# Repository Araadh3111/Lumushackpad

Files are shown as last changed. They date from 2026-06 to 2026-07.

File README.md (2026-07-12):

# Lumuspad

A 5-key macropad with a rotary encoder, OLED screen and RGB underglow.
Based on HackClub's MacroPad Guide: https://hackpad.hackclub.com/guide

----------------------------------
What it does:-

- SW1: New tab (Ctrl+T)
- SW2: Cycles the OLED animation (Cyberpunk scanner / Equalizer / Stealth logo)
- SW3: Launches VS Code
- SW4: Opens YouTube in Brave
- SW5: Leaves the current call (Zoom / Teams / Discord)
- Knob: Volume up/down, press to mute
- 5x SK6812 RGB LEDs running a rainbow swirl

----------------------------------
File Structure:-

--CAD

  -luma_bottom_tray.step

  -luma_spacer.step

  -luma_switch_plate.step

  -luma_case_assembled.step

--Firmware (QMK, builds automatically via GitHub Actions -> .uf2)

  -keyboard.json

  -keymap.c

  -config.h

  -rules.mk

--PCB (schematics + pcb)

  -Luma pcb.kicad_pro / .kicad_sch / .kicad_pcb

----------------------------------
Schematic:-

Heres my schematic I forgot to organise :(



PCB:-
Here is my pcb I imported the silkscreen from pinterest then used inbuilt image converter to copy it and paste it on the pcb

PS:- the led dioded do not intersect with the switch as they are inverted and on the other side! more can be seen from the next two screenshots





Case:-
here is my case, I was aiming for one cyberpunkish case and made it its screwable from the corners(m3 screws)


Assembled:-
here is the assembled file! (ps: the pins will be bended!)


---------------------------------
Ai usage:-
I used claude to help me make the qmk firmware! rest build was done by me
----------------------------------
BOM:-

-1x Seeed XIAO RP2040

-5x MX-style Switches

-5x DSA Keycaps

-1x EC11 Rotary Encoder (with push button)

-1x 0.91" 128x32 OLED Display (I2C)

-5x SK6812 MINI RGB LEDs

-1x Resistor (RGB data line)

-5x 100nF Capacitors and one μF Capacitor in the pcb

-1x Case (3 printed parts: bottom tray, spacer, switch plate)

No diodes needed — every switch has its own pin (direct wiring).

refer to BOM.CSV
+ pcb printing fund

----------------------------------
Firmware:-

Compiled automatically by GitHub Actions on every push.
Grab the latest lumuspad_firmware artifact from the Actions tab,
hold the BOOT button on the XIAO while plugging in USB,
and drag the .uf2 onto the RPI-RP2 drive.
----------------------------------

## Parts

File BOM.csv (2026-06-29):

Quantity | Part | Notes
1 | Seeed XIAO RP2040
5 | MX-style Switches
5 | DSA Keycaps
1 | EC11 Rotary Encoder | With push button
1 | 0.91" 128x32 OLED Display | I2C
5 | SK6812 MINI RGB LEDs
1 | Resistor | RGB data line
5 | 100nF Capacitors | In the PCB
1 | µF Capacitor | In the PCB
1 | Case | 3 printed parts: bottom tray, spacer, switch plate

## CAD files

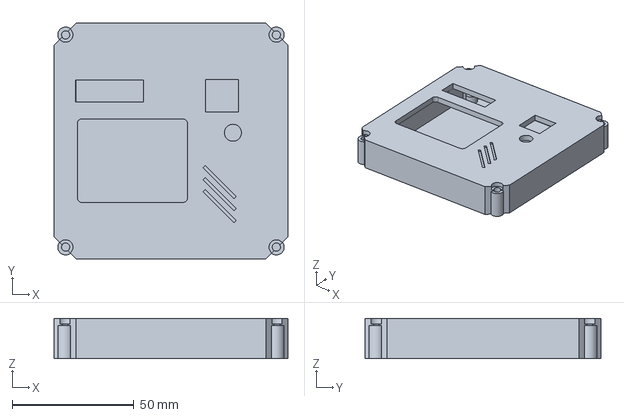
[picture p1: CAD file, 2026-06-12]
CAD/luma_case_assembled.step
96.2 x 96.9 x 16.5 mm

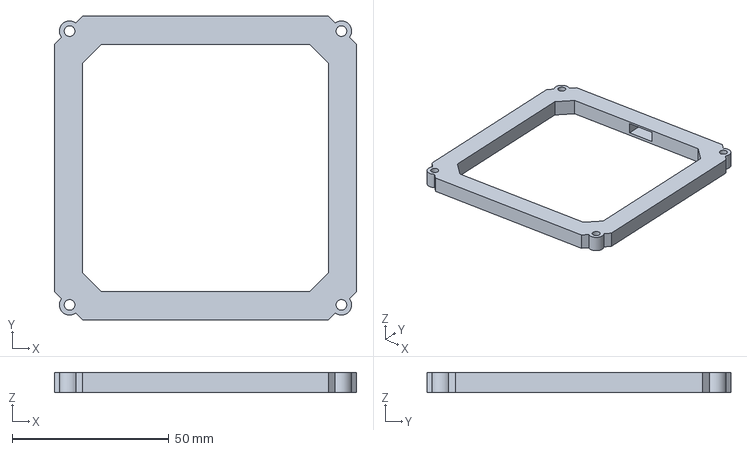
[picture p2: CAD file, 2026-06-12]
Production/luma_spacer.step
96.2 x 96.9 x 6.50 mm

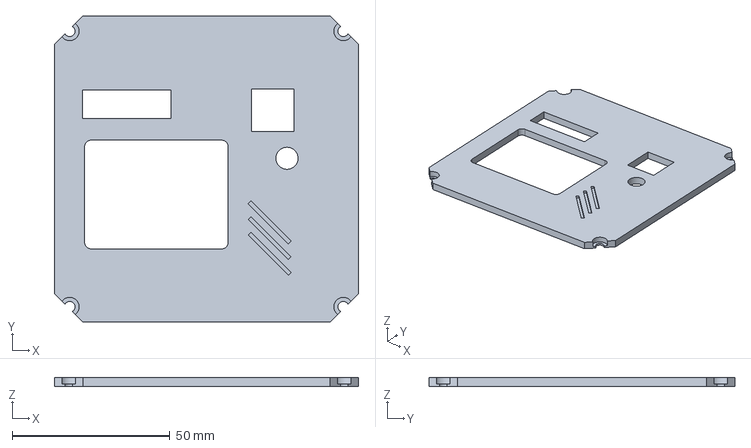
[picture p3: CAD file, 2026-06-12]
Production/luma_switch_plate.step
96.2 x 96.9 x 3.00 mm

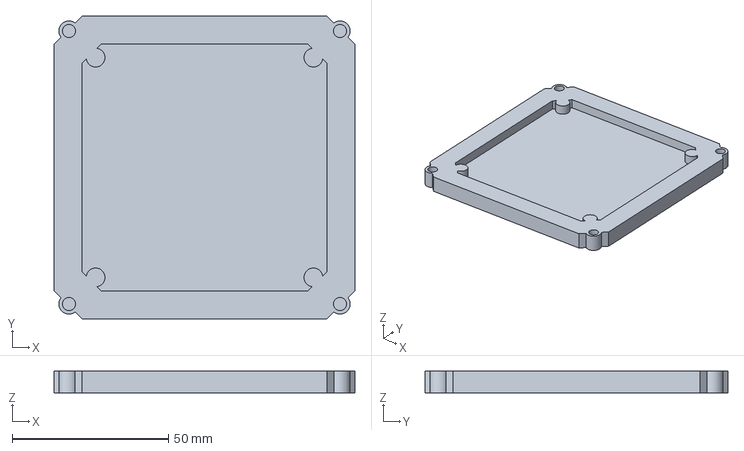
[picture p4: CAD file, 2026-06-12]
Production/luma_bottom_tray.step
96.2 x 96.9 x 7.00 mm

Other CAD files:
CAD/luma_bottom_tray.f3d

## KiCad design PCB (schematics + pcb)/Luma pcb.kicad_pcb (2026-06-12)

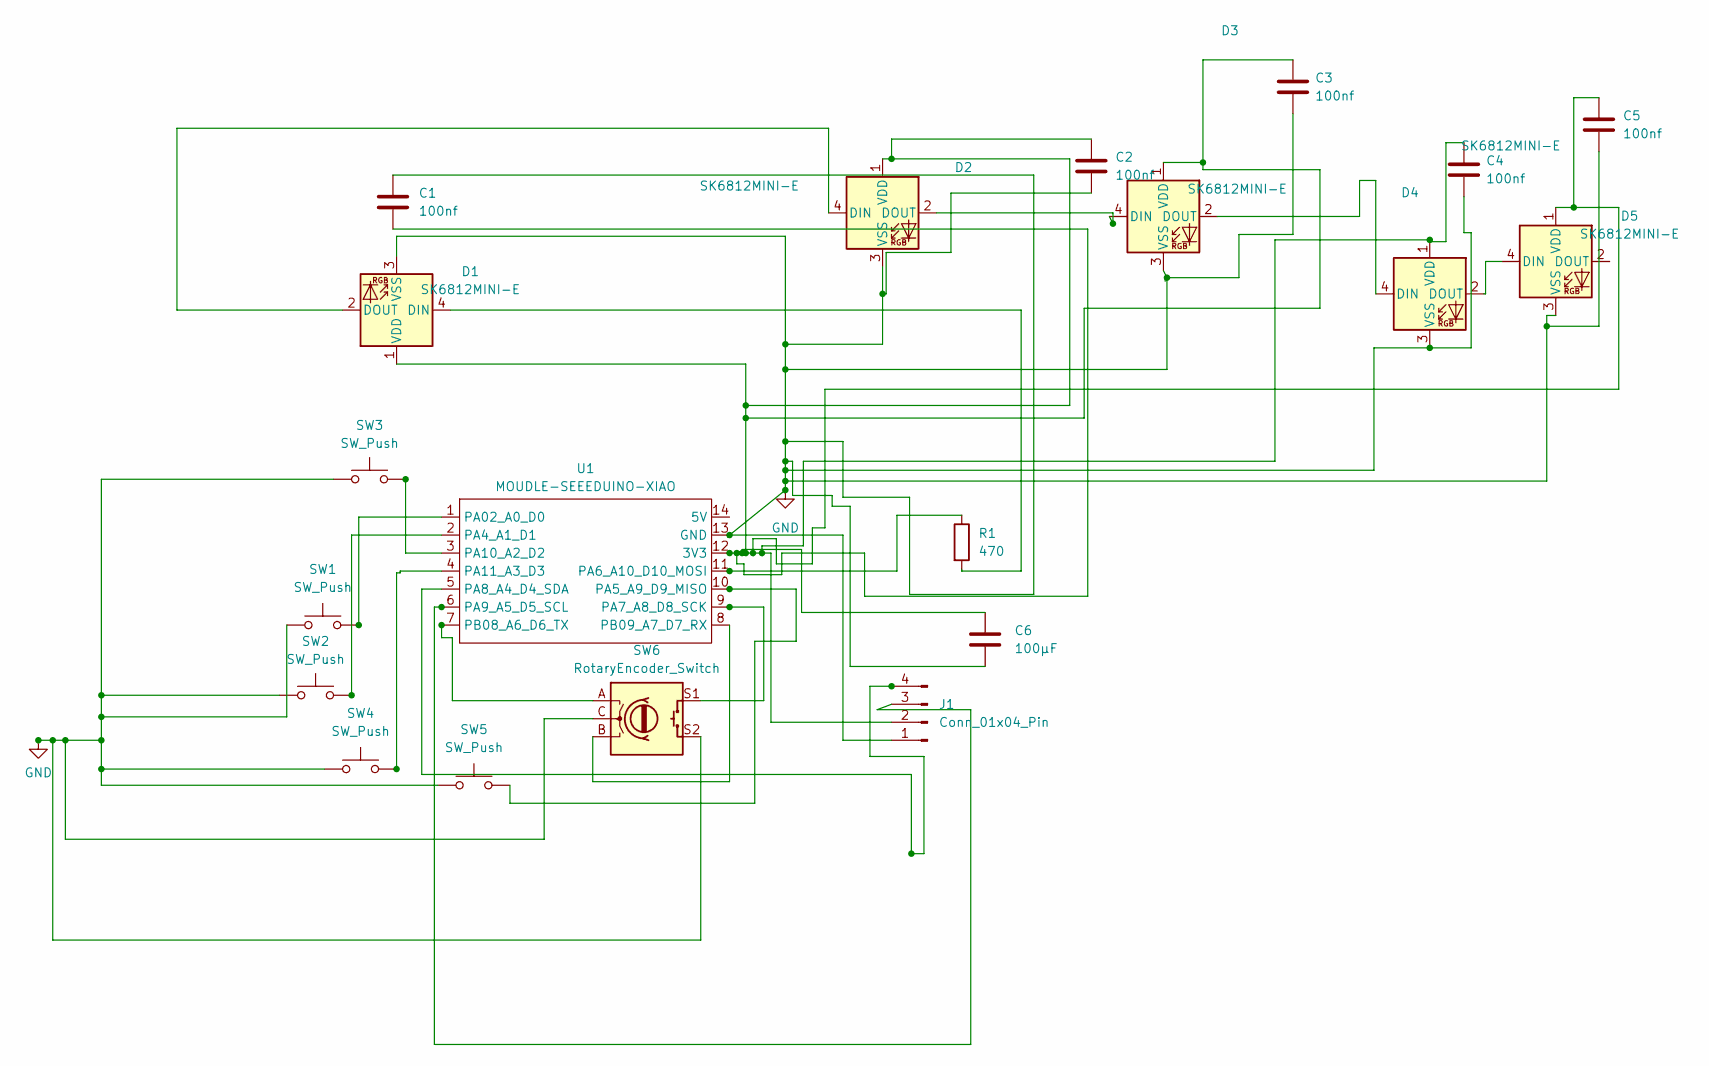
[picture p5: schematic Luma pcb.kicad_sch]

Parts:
C1, C2, C3, C4, C5: 100nf; C_0805_2012Metric_Pad1.18x1.45mm_HandSolder
C6: 100µF; CP_Radial_D5.0mm_P2.00mm
D1, D2, D3, D4, D5: SK6812MINI-E; SK6812MINI-E_fixed
J1: Conn_01x04_Pin; FanPinHeader_1x04_P2.54mm_Vertical
R1: 470; R_Axial_DIN0207_L6.3mm_D2.5mm_P7.62mm_Horizontal
SW1, SW2, SW3, SW4, SW5: SW_Push; SW_Cherry_MX_1.00u_PCB
SW6: RotaryEncoder_Switch; RotaryEncoder_Alps_EC11E-Switch_Vertical_H20mm
U1: MOUDLE-SEEEDUINO-XIAO; XIAO-Generic-Hybrid-14P-2.54-21X17.8MM

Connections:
GND: C1.1, C2.2, C3.2, C4.2, C5.2, C6.2, D1.3 (VSS), D2.3 (VSS), D3.3 (VSS), D4.3 (VSS), D5.3 (VSS), J1.1, SW1.1, SW2.1, SW3.1, SW4.1, SW5.1, SW6.C, SW6.S2, U1.13 (GND)
unnamed: D1.4 (DIN), R1.2
unnamed: D1.2 (DOUT), D2.4 (DIN)
unnamed: C1.2, C2.1, C3.1, C4.1, C5.1, C6.1, D1.1 (VDD), D2.1 (VDD), D3.1 (VDD), D4.1 (VDD), D5.1 (VDD), J1.2, U1.12 (3V3)
unnamed: D2.2 (DOUT), D4.4 (DIN)
unnamed: D3.4 (DIN), D4.2 (DOUT)
unnamed: D3.2 (DOUT), D5.4 (DIN)
unnamed: J1.3, U1.6 (PA9_A5_D5_SCL)
unnamed: J1.4, U1.5 (PA8_A4_D4_SDA)
unnamed: SW1.2, U1.1 (PA02_A0_D0)
unnamed: SW2.2, U1.2 (PA4_A1_D1)
unnamed: SW5.2, U1.10 (PA5_A9_D9_MISO)
unnamed: R1.1, U1.11 (PA6_A10_D10_MOSI)
unnamed: SW6.S1, U1.9 (PA7_A8_D8_SCK)
unnamed: SW3.2, U1.3 (PA10_A2_D2)
unnamed: SW4.2, U1.4 (PA11_A3_D3)
unnamed: SW6.A, U1.7 (PB08_A6_D6_TX)
unnamed: SW6.B, U1.8 (PB09_A7_D7_RX)

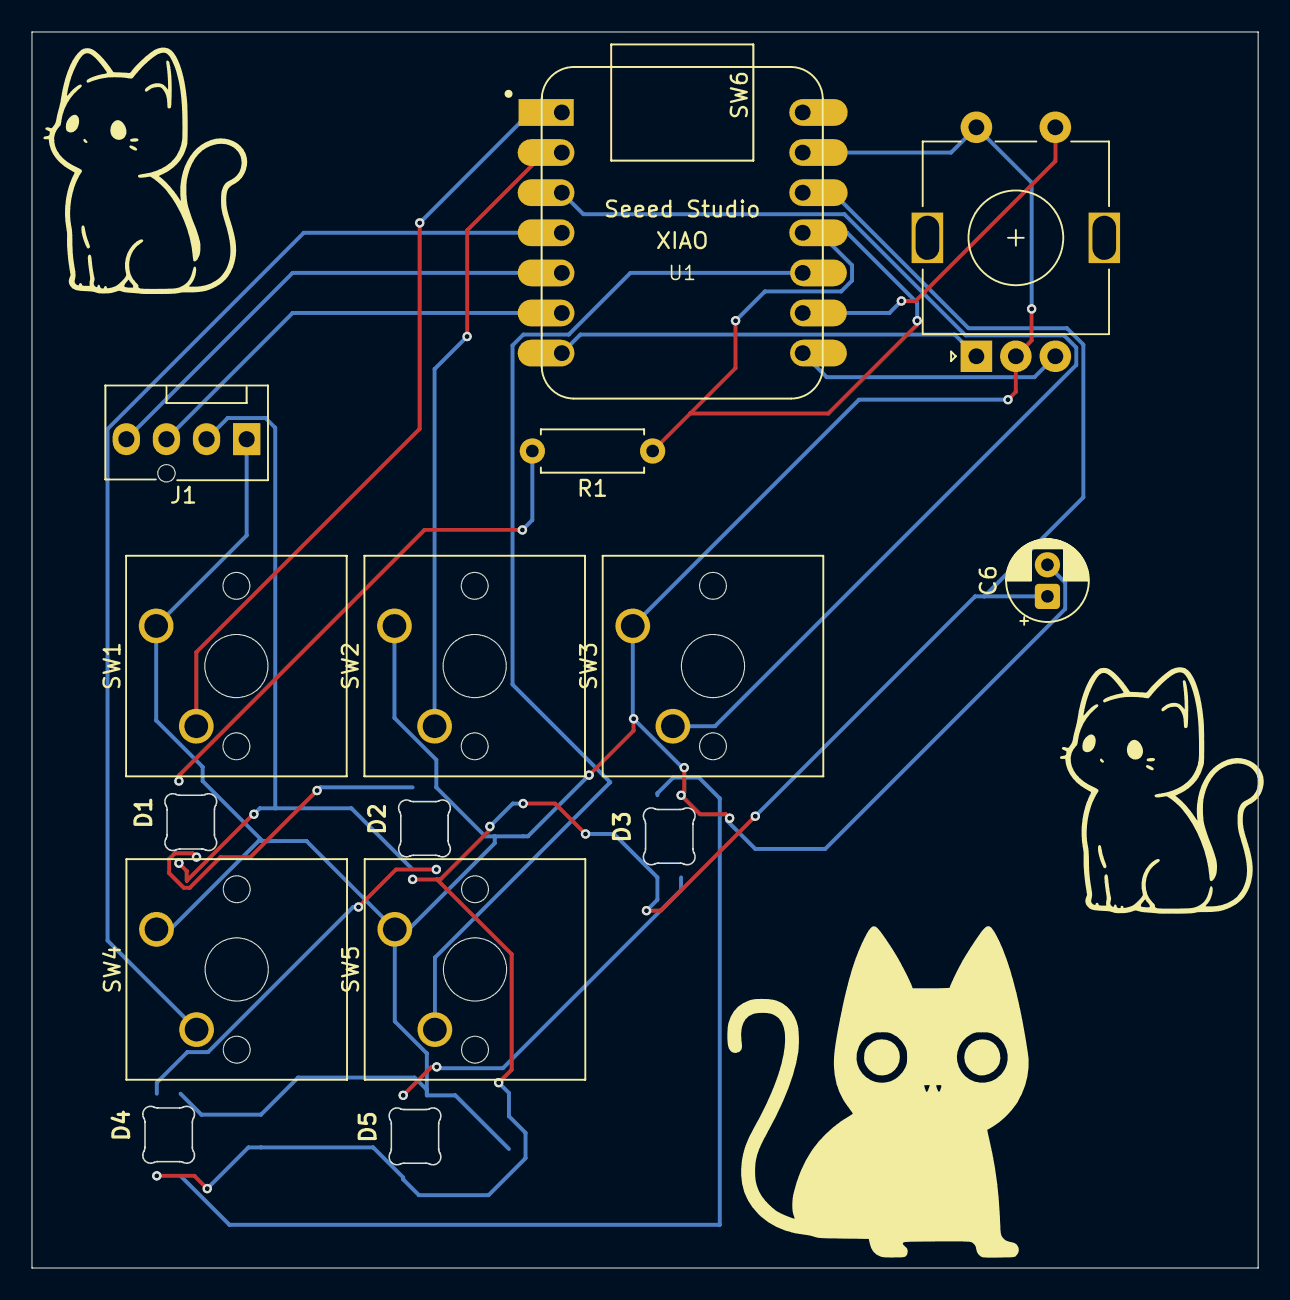
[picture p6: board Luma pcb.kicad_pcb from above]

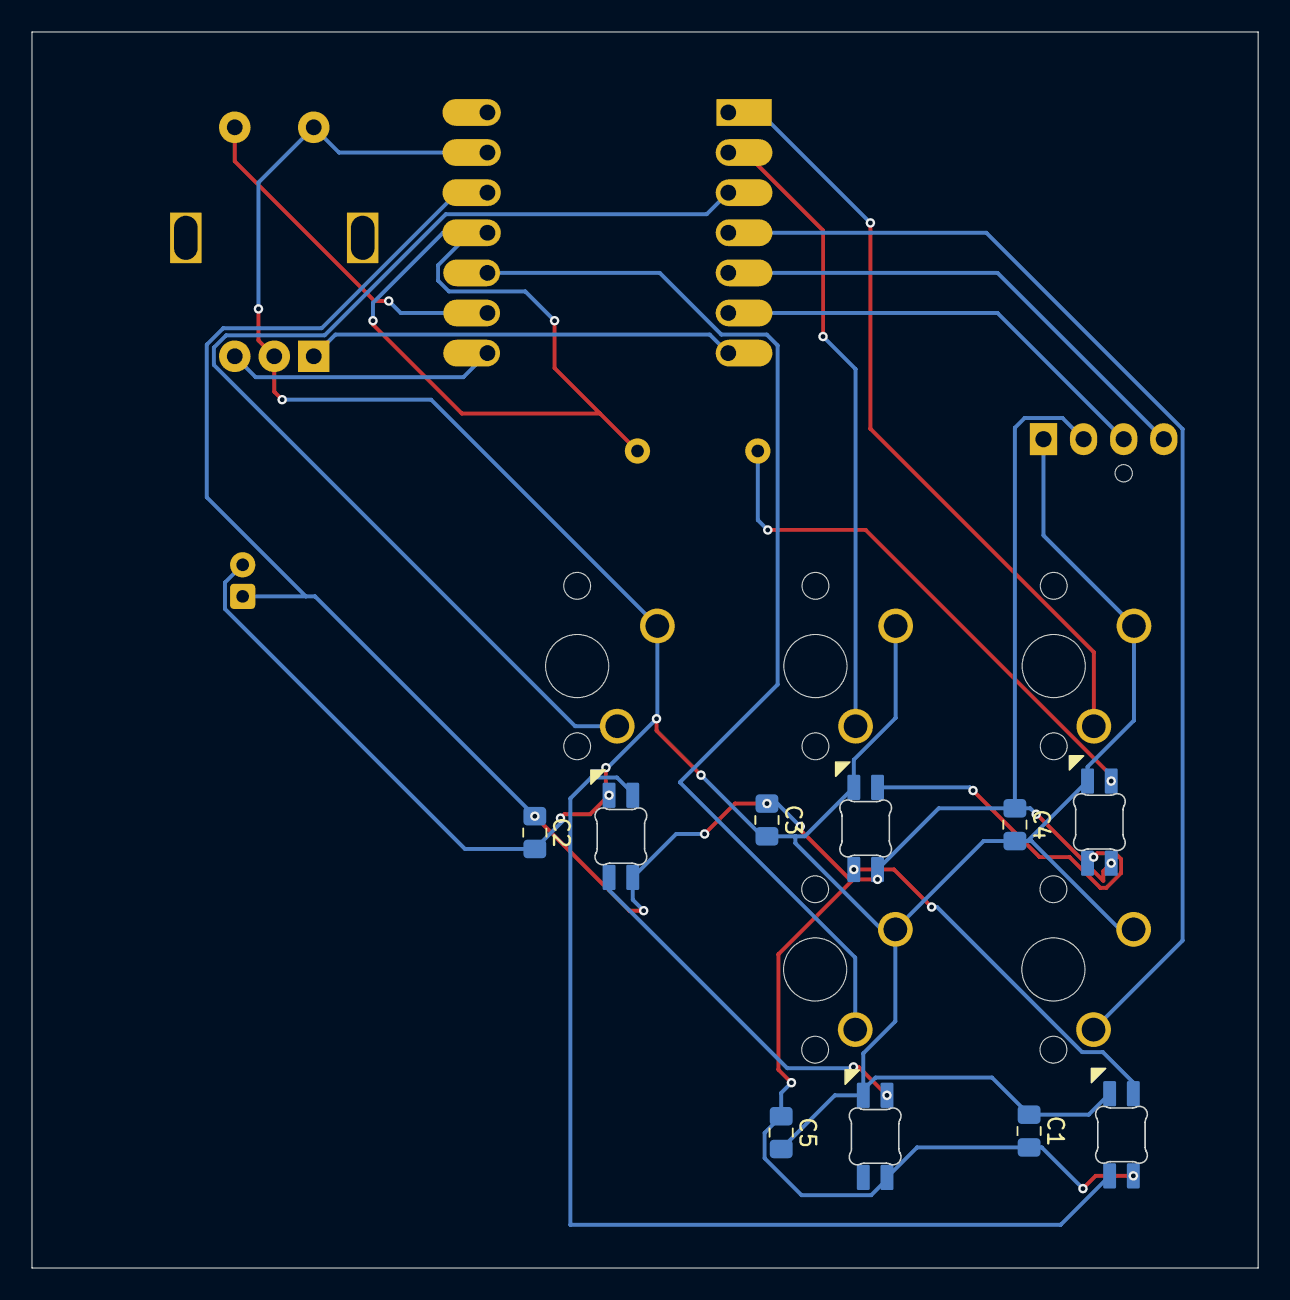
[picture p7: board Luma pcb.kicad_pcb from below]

Board: 2 copper layers, 77.6 x 78.3 mm, 20 parts (5 on the bottom side), 18 nets.

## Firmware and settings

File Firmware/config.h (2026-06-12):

#pragma once

// OLED sits on the XIAO RP2040 hardware I2C: D4/SDA = GP6, D5/SCL = GP7 (I2C1)
#define I2C_DRIVER I2CD1
#define I2C1_SDA_PIN GP6
#define I2C1_SCL_PIN GP7

// 0.91" SSD1306, 128x32
#define OLED_BRIGHTNESS 128
#define OLED_TIMEOUT 60000

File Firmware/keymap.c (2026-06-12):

#include QMK_KEYBOARD_H
#include <stdio.h>

// Custom keycodes for app-launcher macros and the OLED mode switch
enum custom_keycodes {
    OPEN_VSCODE = SAFE_RANGE,
    OPEN_BRAVE_YT,
    LEAVE_CALL,
    ANIM_CYCLE
};

// Physical order matches the direct-pin matrix in keyboard.json:
// SW1..SW5 are the keys, SW6 is the rotary encoder's push button.
const uint16_t PROGMEM keymaps[][MATRIX_ROWS][MATRIX_COLS] = {
    [0] = LAYOUT(
        LCTL(KC_T),       // SW1: New Tab (Ctrl + T)
        ANIM_CYCLE,       // SW2: Cycle OLED animation mode
        OPEN_VSCODE,      // SW3: Launch VS Code
        OPEN_BRAVE_YT,    // SW4: Open YouTube in Brave
        LEAVE_CALL,       // SW5: Leave call (Zoom / Teams / Discord)
        KC_MUTE           // SW6: Encoder push = mute audio
    )
};

// ---------------------------------------------------------------------------
// Shared state for the OLED status line
// ---------------------------------------------------------------------------
static uint8_t anim_mode = 0;
static char    last_action[12] = "READY";

static void set_action(const char *name) {
    snprintf(last_action, sizeof(last_action), "%s", name);
}

// ---------------------------------------------------------------------------
// Macros: launch apps through the Windows Run dialog (Win+R)
// ---------------------------------------------------------------------------
bool process_record_user(uint16_t keycode, keyrecord_t *record) {
    if (!record->event.pressed) {
        return true;
    }

    switch (keycode) {
        case ANIM_CYCLE:
            anim_mode = (anim_mode + 1) % 3;
            return false;

        case OPEN_VSCODE:
            SEND_STRING(SS_LGUI("r") SS_DELAY(150) "code" SS_TAP(X_ENTER));
            set_action("VSCODE");
            return false;

        case OPEN_BRAVE_YT:
            SEND_STRING(SS_LGUI("r") SS_DELAY(150) "brave youtube.com" SS_TAP(X_ENTER));
            set_action("YOUTUBE");
            return false;

        case LEAVE_CALL:
            // Zoom end-call first, then a Ctrl+Shift+H backup for Teams/Discord
            SEND_STRING(SS_LALT("h") SS_DELAY(50) SS_LCTL(SS_LSFT("h")));
            set_action("END CALL");
            return false;

        case LCTL(KC_T):
            set_action("NEW TAB");
            return true;

        case KC_MUTE:
            set_action("MUTE");
            return true;
    }
    return true;
}

// ---------------------------------------------------------------------------
// Rotary encoder: volume control
// ---------------------------------------------------------------------------
#ifdef ENCODER_ENABLE
bool encoder_update_user(uint8_t index, bool clockwise) {
    if (clockwise) {
        tap_code(KC_VOLU);
        set_action("VOL +");
    } else {
        tap_code(KC_VOLD);
        set_action("VOL -");
    }
    return false;
}
#endif

// ---------------------------------------------------------------------------
// OLED: three animated modes on the 128x32 screen (4 rows x 21 columns)
// ---------------------------------------------------------------------------
#ifdef OLED_ENABLE

#define ANIM_FRAME_MS 80

static uint8_t  frame       = 0;
static uint32_t frame_timer = 0;

// Small deterministic noise generator so the equalizer bars dance
static uint8_t noise8(uint8_t x, uint8_t t) {
    uint8_t n = (uint8_t)(x * 37 + t * 13 + 7);
    n ^= n << 3;
    n ^= n >> 2;
    return n;
}

// Mode 0: bouncing scanner beam, cyberpunk style
static void render_cyberpunk(void) {
    char bar[22];

    oled_write_ln("MODE: CYBERPUNK", false);

    uint8_t pos = frame % 36;            // bounce across 19 cells
    if (pos > 18) pos = 36 - pos;
    bar[0] = '[';
    for (uint8_t i = 0; i < 19; i++) {
        if (i == pos)                          bar[i + 1] = '#';
        else if (i + 1 == pos || i == pos + 1) bar[i + 1] = '=';
        else                                   bar[i + 1] = '-';
    }
    bar[20] = ']';
    bar[21] = '\0';
    oled_write_ln(bar, false);

    oled_write_ln((frame & 4) ? "SYS :: ONLINE_" : "SYS :: ONLINE ", false);
    oled_write("> ", false);
    oled_write_ln(last_action, false);
}

// Mode 1: 21-column equalizer made of stacked rows
static void render_equalizer(void) {
    char rows[3][22];

    oled_write_ln("MODE: EQUALIZER", false);

    for (uint8_t col = 0; col < 21; col++) {
        uint8_t h = noise8(col, frame) % 4;  // bar height 0..3
        rows[0][col] = (h > 2) ? '|' : ' ';
        rows[1][col] = (h > 1) ? '|' : ' ';
        rows[2][col] = (h > 0) ? '|' : '.';
    }
    for (uint8_t r = 0; r < 3; r++) {
        rows[r][21] = '\0';
        oled_write_ln(rows[r], false);
    }
}

// Mode 2: minimal breathing logo
static void render_stealth(void) {
    static const char *pulse[4] = {
        "    -  LUMUS PAD  -",
        "   --  LUMUS PAD  --",
        "  ---  LUMUS PAD  --",
        "   --  LUMUS PAD  --"
    };

    oled_write_ln("MODE: STEALTH", false);
    oled_write_ln("", false);
    oled_write_ln(pulse[(frame >> 2) & 3], false);
    oled_write("> ", false);
    oled_write_ln(last_action, false);
}

bool oled_task_user(void) {
    if (timer_elapsed32(frame_timer) > ANIM_FRAME_MS) {
        frame_timer = timer_read32();
        frame++;
    }

    oled_set_cursor(0, 0);
    switch (anim_mode) {
        case 0:  render_cyberpunk(); break;
        case 1:  render_equalizer(); break;
        default: render_stealth();   break;
    }
    return false;
}
#endif

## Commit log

2026-06-08 Initial commit: Completed schematics and initial PCB footprint layout
    [Luma pcb.kicad_pcb, Luma pcb.kicad_sch]
2026-06-08 Add KiCad backup and temporary files to .gitignore
2026-06-12 Add QMK firmware matching PCB netlist, CAD case files, and PCB updates
    Firmware (XIAO RP2040):
    - Add keyboard.json with correct pins traced from the PCB netlist:
    switches on GP26/GP27/GP28/GP29/GP4, encoder on GP0/GP1 with push
    button on GP2, OLED I2C on GP6/GP7, 5x SK6812 RGB LEDs on GP3
    - Fix keymap.c: invalid X_LSHIFT keycode, KC_NO interception replaced
    with a proper ANIM_CYCLE keycode, encoder push mapped to mute
    - Add three animated OLED modes (scanner, equalizer, breathing logo)
    with a live last-action status line
    - Enable RGBLIGHT for the onboard LED chain
    Also add CAD case STEP files and gitignore editor auto-backups.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
    [Luma pcb.kicad_pcb, Luma pcb.kicad_sch, luma_bottom_tray.step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]
2026-06-12 Remove KiCad auto-backups and local prefs from the repo
    The Luma pcb-backups zips, .history, and .kicad_prl were tracked since
    the initial commit; gitignore entries alone do not untrack them.
2026-06-12 Add README with project overview, BOM, and flashing guide
2026-06-12 Add images for schematic, PCB, and case in README
    Updated README.md to include schematic, PCB, and case images.
2026-06-12 Add production folder
    [luma_bottom_tray.step, luma_spacer.step, luma_switch_plate.step]
2026-06-12 Update PCB design
    [Luma pcb.kicad_pcb]
2026-06-12 Revise README.md for clarity and details
    Updated descriptions for schematic, PCB, and case sections. Clarified capacitor count in the components list.
2026-06-12 added text to the bottom tray
    [luma_bottom_tray.f3d]
2026-06-12 added small changes to pcb
    [Luma pcb.kicad_pcb]
2026-06-17 Update README with PCB printing fund information
    Added section about PCB printing fund to README.
2026-06-29 Add BOM entries for components and quantities
    [bom.csv]
2026-06-29 added BOM
    [BOM.csv]
2026-07-08 Add 'Assembled' section to README
    Added an 'Assembled' section with an image to the README.
2026-07-08 Modify assembled file description in README
    Updated the description of the assembled file to note that the pins will be bended.
